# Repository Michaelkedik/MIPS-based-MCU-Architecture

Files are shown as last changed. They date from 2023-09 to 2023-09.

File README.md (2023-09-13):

# MIPS based MCU Architecture

In this project, I developed an MCU based on the MIPS architecture, incorporating Memory-Mapped I/O, a Basic Timer, and an Interrupt Controller.
The CPU uses a Single Cycle MIPS architecture and is capable of performing full instruction set of simple MIPS.
The design is located on Altera Board and the MIPS architecture is Harvard architecture in order to increase the throughput.
The architecture includes a MIPS ISA compatible CPU with data and program memory for hosting data and code.
The CPU have a standard MIPS register file. The top level and the MIPS core are structural. 
The figure below illustrates the design.



The GPIO is a simple decoder with buffer registers mapped to data address (Higher than data memory) that enables the CPU to output data to LEDs and 7-Segment and to read the Switches state.
The Data Address Space is 32-bit WORD aligned where the address word is 0 ... 0 A11 ... A0 with partial mapping that contains Data Memory and Memory Mapped I/O.
The figure below illustrates the design.



The Basic Timer was designed to facilitate standard timer functions as well as the generation of PWM signals through the utilization of the output compare mode.
The figure below illustrates the design.



The Interrupt Controller was specifically crafted to manage a range of interrupt types, including those originating from the basic timer.
The figure below illustrates the design.



## Description

The repositories in this project serve the following purposes:

**DUT:** This repository contains VHDL codes for the top entity and components. These codes can be compiled using ModelSim and Quartus via change of basic parameters.

**DOC:** This repository contains project documentation and a README file that provides an explanation of the VHDL files' purpose.

**CODE:** This repository contains assembly code used for verifying the design's functionality.

**TB:** This repository contains Testbench files that were used for ModelSim verification of the design.

**SIM:** This repository contains ".do" files used for ModelSim simulation.

**QUARTUS:** This repository contains project files such as ".sof," SDC, and STP files, which are used for Quartus compilation and verification of the design.

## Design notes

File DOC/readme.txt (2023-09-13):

1)Top- The top entity, Synchronizes the MIPS, GPIO and the BUS
2)MIPS - The CPU, Synchronizes all the other components of the CPU
3)IFETCH - Get the instruction and advance the PC according to the relevant adress
4)IDECODE - Decode the instruction and read and write from the register file
5)DMEMORY- Read or write from the data memory
6)EXECUTE- Performs all the logic or arithmetic actions
7)CONTROL - Produces the control signals that are needed for the instructions to be executed
8)GPIO - General IO Component, Synchronizes all the IO Components
9)BidirPin - Used as data bus
10)Timer - Basic timer used for interrupts and to generate PWM signal using output compare mode
11)INTCTL - Interrupt controller, responsible for handling the interrupts
12)Hex - Decoder for the HEX outputs
13)D_latch - a simple D_latch, used in the INTCTL

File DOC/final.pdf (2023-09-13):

# מעבדת ארכיטקטורת מעבדים מתקדמת ומאיצי חומרה

# פרויקט גמר

# מיכאל קדיק 316645415 עמית ניסני 205664345

## תיאור הפרויקט

,Single Cycle MIPS על | המבוסס | CPU MIPS based MCU | לייצר | התבקשנו | זה | בפרויקט
המשתמש בO/I Mapped Memory ובעל תמיכה בפסיקות. לשם כך, יצרנו יחידות כמו GPIO, INTCTL ו-Timer בכדי לאפשר את כל הנדרש.

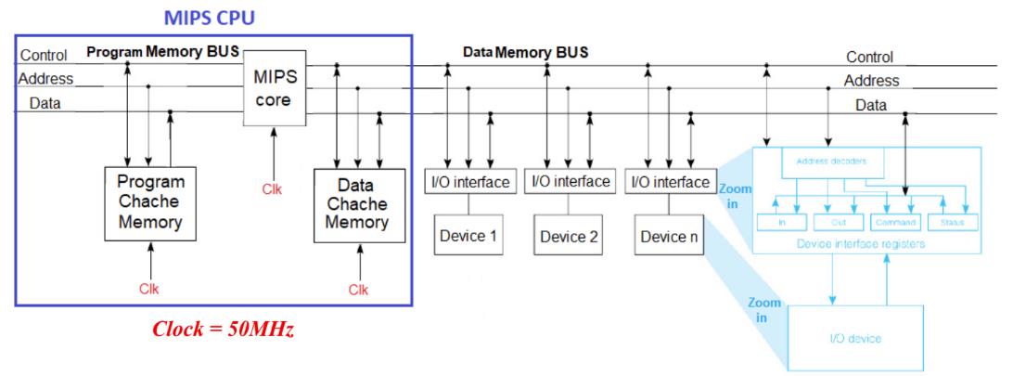
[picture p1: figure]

את ה-GPIO מימשנו עפ"י הנדרש בפרויקט כפי שצוין באיור הבא.

Figure 1. System architecture

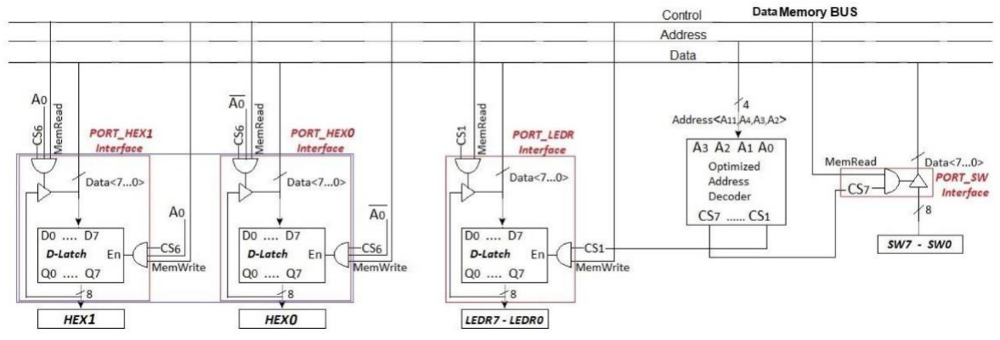
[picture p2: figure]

Figure 2. GPIO peripheral connection using Memory Mapped I/O

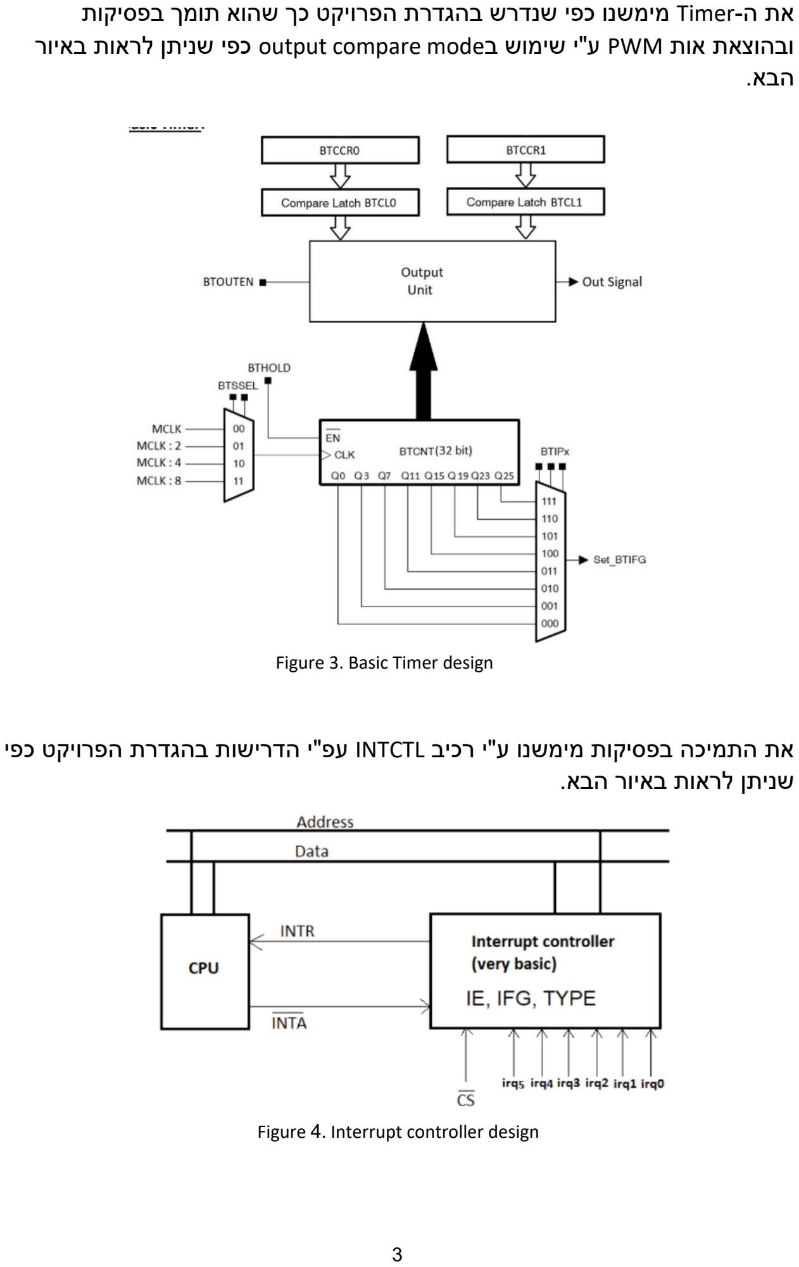
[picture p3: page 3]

את ה-Timer מימשנו כפי שנדרש בהגדרת הפרויקט כך שהוא תומך בפסיקות ובהוצאת אות PWM ע"י שימוש בmode compare output כפי שניתן לראות באיור הבא.

את התמיכה בפסיקות מימשנו ע"י רכיב INTCTL עפ"י הדרישות בהגדרת הפרויקט כפי שניתן לראות באיור הבא.

Figure 3. Basic Timer design

Figure 4. Interrupt controller design

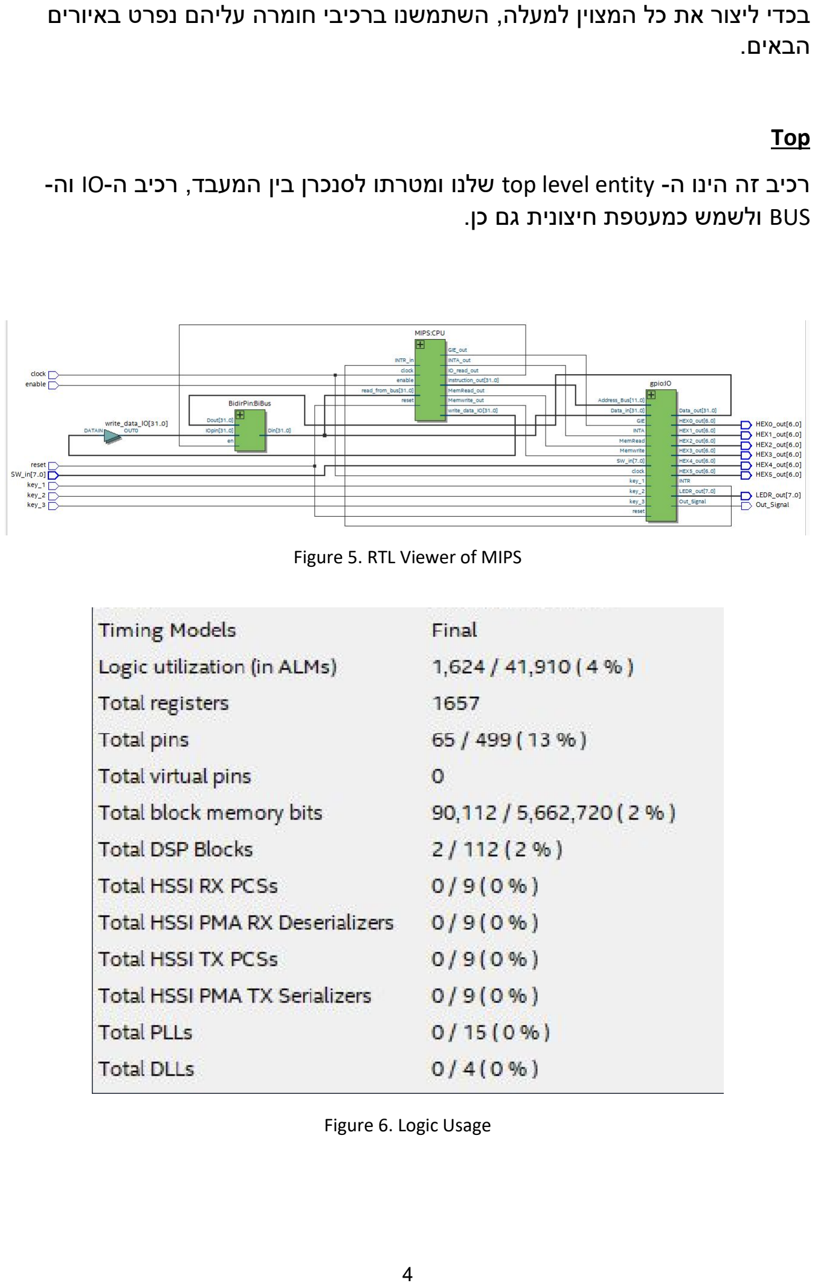
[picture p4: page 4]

בכדי ליצור את כל המצוין למעלה, השתמשנו ברכיבי חומרה עליהם נפרט באיורים הבאים.

Top

רכיב זה הינו ה- entity level top שלנו ומטרתו לסנכרן בין המעבד, רכיב ה-IO וה-BUS ולשמש כמעטפת חיצונית גם כן.

Figure 5. RTL Viewer of MIPS

Figure 6. Logic Usage

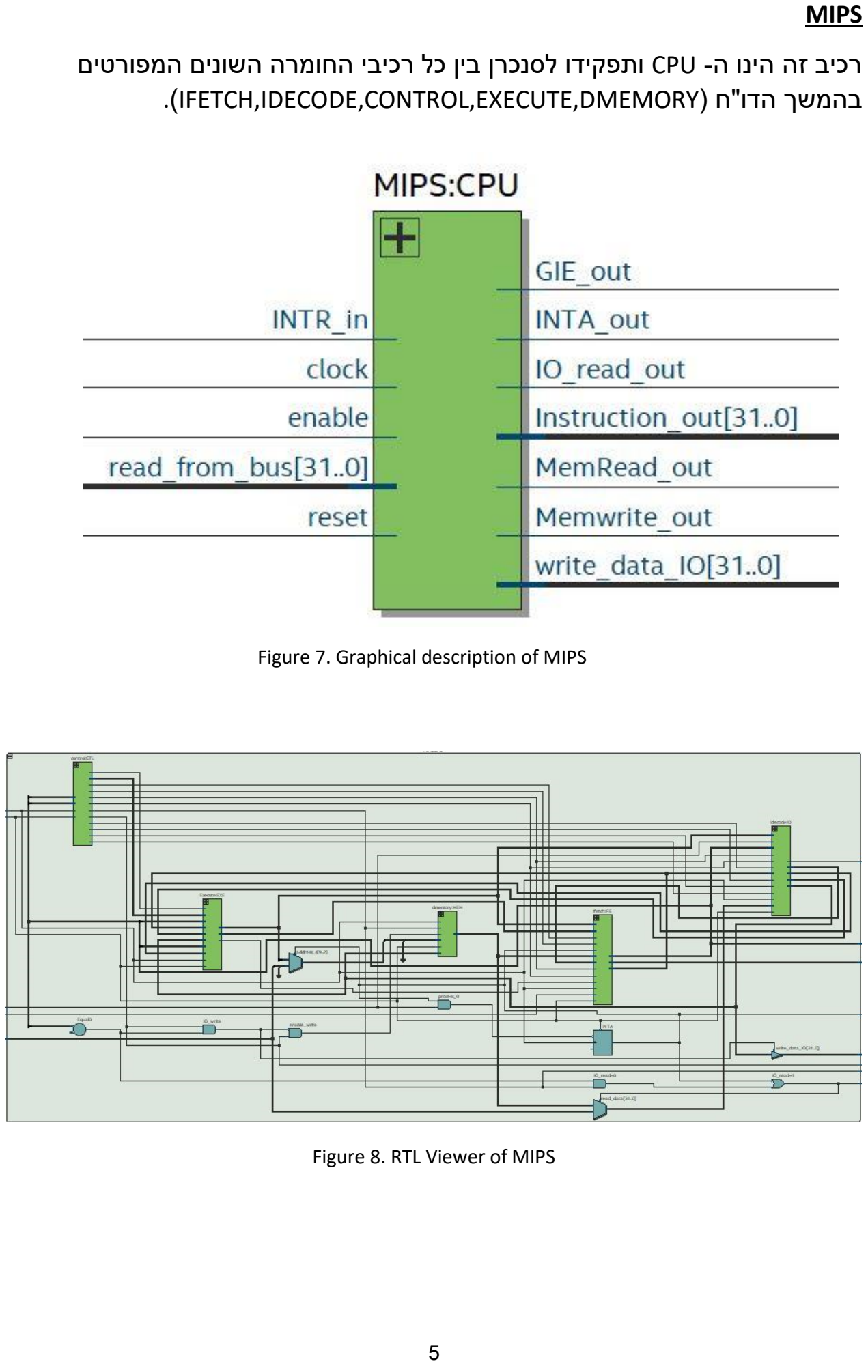
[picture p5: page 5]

MIPS

רכיב זה הינו ה- CPU ותפקידו לסנכרן בין כל רכיבי החומרה השונים המפורטים
.)IFETCH,IDECODE,CONTROL,EXECUTE,DMEMORY( ח"הדו | בהמשך

Figure 7. Graphical description of MIPS

Figure 8. RTL Viewer of MIPS

Name | Direction | Size | Functionality
clock | IN | 1 | שעון
reset | IN | 1 | אתחול
enable | IN | 1 | PC אפשור
INTR_in | IN | 1 | בקרה
read_from_bus | IN | 32 | BUS -מה מידע קריאת
IO_read_out | OUT | 1 | בקרה
write_data_IO | OUT | 32 | BUS -ה אל מידע כתיבת
| | | פקודה שמתבצעת כרגע 32 OUT out_Instruction
MemRead_out | OUT | 1 | בקרה
Memwrite_out | OUT | 1 | בקרה
INTA_out | OUT | 1 | בקרה
GIE_out | OUT | 1 | בקרה

Table 1. Port Table of MIPS

IFETCH

תפקידו של רכיב זה הוא להביא את הפקודה שיש לבצע ולקדם את ה-pc לפקודה הבאה )שאינה בהכרח הפקודה העוקבת, כמו למשל אם יש jump).

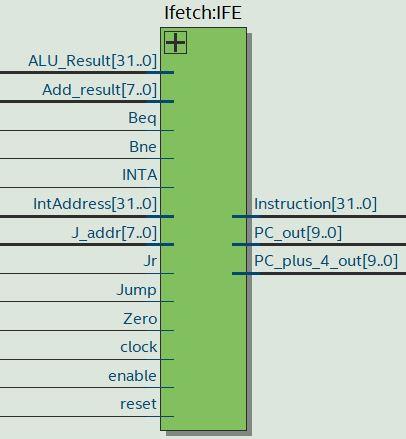
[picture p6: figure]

Figure 9. Graphical description of IFETCH

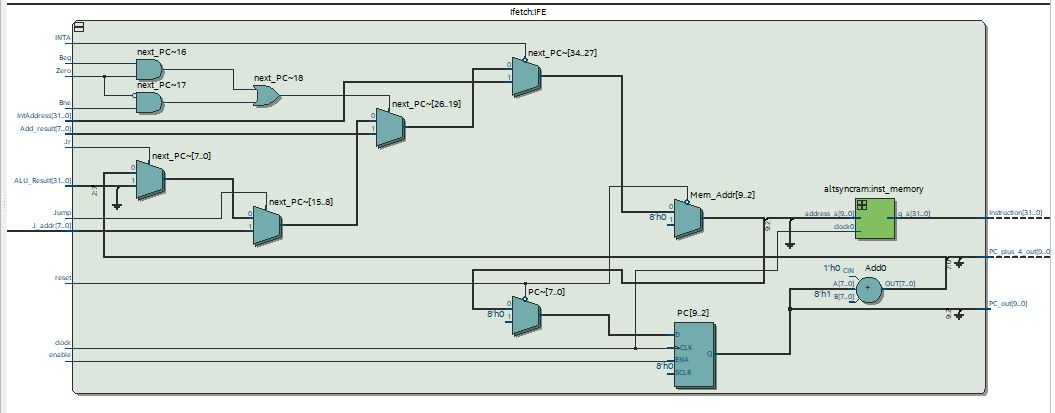
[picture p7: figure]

Figure 10. RTL Viewer of IFETCH

Name | Direction | Size | Functionality
clock | IN | 1 | שעון
reset | IN | 1 | אתחול
enable | IN | 1 | PC אפשור
Add_result | IN | 8 | הסתעפות כתובת
| | | משמש לפקודת קפיצה 32 IN Result_ALU
IntAddress | IN | 32 | כתובת למיקופ בוקטור הפסיקה
J_addr | IN | 8 | קפיצה כותבת
INTA | IN | 1 | בקרה
Jump | IN | 1 | בקרה
Zero | IN | 1 | בקרה
Beq | IN | 1 | בקרה
Bne | IN | 1 | בקרה
Jr | IN | 1 | בקרה
| | | פקודה לביצוע 32 OUT Instruction
| | | כתובת של פקודה הבאה 10 OUT out_4_plus_PC
| | | כתובת של פקודה נוכחית 10 OUT out_PC

Table 2. Port Table of IFETCH

IDECODE

תפקידו של רכיב זה הוא לפענח את הפקודה שיש לבצע , בנוסף ברכיב זה נמצא הfile register ולכן מתבצעת בו גם כתיבה לרגיסטרים.

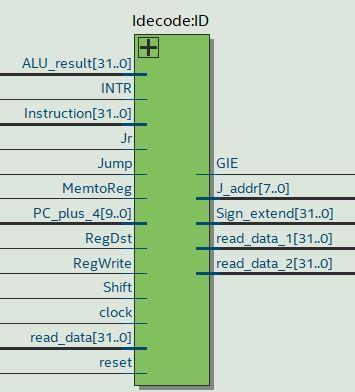
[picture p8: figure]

Figure 11. Graphical description of IDECODE

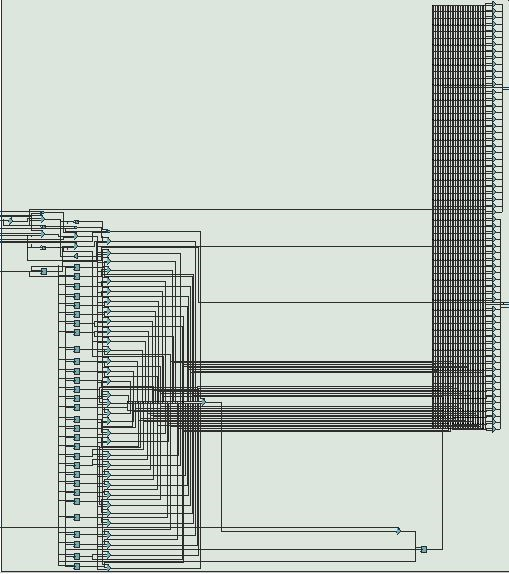
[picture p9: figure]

Figure 12. RTL Viewer of IDECODE

Name | Direction | Size | Functionality
clock | IN | 1 | שעון
reset | IN | 1 | אתחול
| | | הפקודה הנוכחית לפענוח 32 IN Instruction
read_data | IN | 32 | המידע בכתיבה לרגיסטרים
ALU_result | IN | 32 | ALU -ב הפעולה תוצאת
RegWrite | IN | 1 | בקרה
MemtoReg | IN | 1 | בקרה
RegDst | IN | 1 | בקרה
Jump | IN | 1 | בקרה
Jr | IN | 1 | בקרה
Shift | IN | 1 | בקרה
INTR | IN | 1 | בקרה
PC_plus_4 | IN | 10 | כתובת של הפקודה הבאה לביצוע
read_data_1_out | OUT | 32 | 1 מרגיסטר המידע
read_data_2_out | OUT | 32 | 2 מרגיסטר המידע
Sign_extend | OUT | 32 | סיגנל מורחב בהתאם לסימן
J_addr | OUT | 8 | קפיצה כתובת
GIE | OUT | 1 | בקרה

Table 3. Port Table of IDECODE

CONTROL

תפקידו של רכיב זה הוא לייצר את קווי הבקרה בהתאם לפקודה הנוכחית.

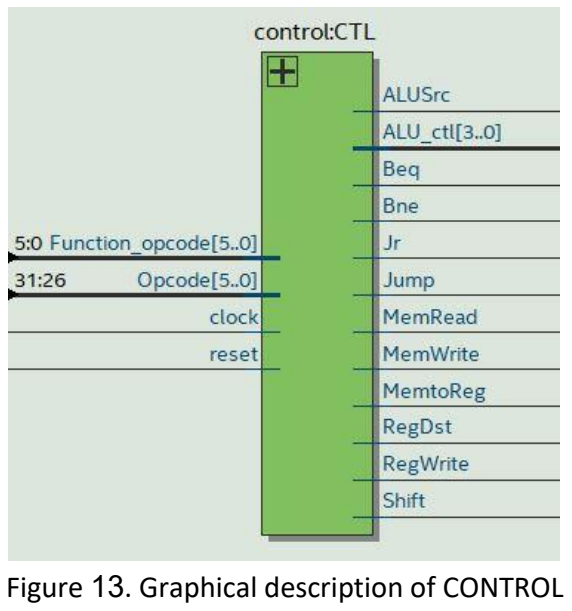
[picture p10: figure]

Figure 13. Graphical description of CONTROL

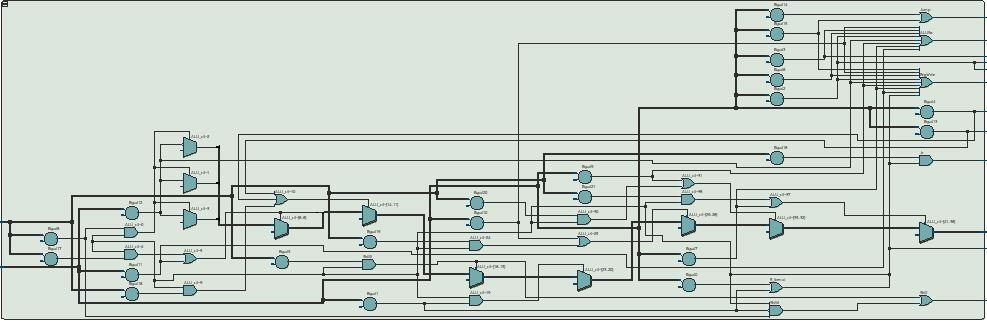
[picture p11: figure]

Figure 14. RTL Viewer of CONTROL

Name | Direction | Size | Functionality
clock | IN | 1 | שעון
reset | IN | 1 | אתחול
| | | ביטים 26-31 בפקודה 6 IN Opcode
Function_opcode | IN | 6 | בפקודה 0-5 ביטים
RegDst | OUT | 1 | קו בקרה לבחירת כתובת יעד הכתיבה לרגיסטר
ALUSrc | OUT | 1 | קו בקרה הבורר איזה מידע יכנס לכניסה B ב-ALU
MemtoReg | OUT | 1 | קו בקרה הבורר בין המידע שיכתב לתוך הרגיסטרים )מהזכרון או מה-ALU)
RegWrite | OUT | 1 | קו בקרה הבורר את כתובת הרגיסטר לכתיבה
MemRead | OUT | 1 | קו בקרה המבחין האם יש לקרוא מהזכרון
MemWrite | OUT | 1 | קו בקרה המבחין האם יש לכתוב לזכרון
Shift | OUT | 1 | קו בקרה המבחין האם יש פעולת shift
Jump | OUT | 1 | קו בקרה המבחין האם יש פעולת קפיצה
Jr | OUT | 1 | קו בקרה המבחין האם יש פעולת קפיצה לתוך ערך השמור ברגיסטר
Beq | OUT | 1 | קו בקרה המבחין האם יש פעולת הסתעפות
Bne | OUT | 1 | קו בקרה המבחין האם יש פעולת הסתעפות
ALU_ctl | OUT | 4 | קו בקרה הבורר איזה פעולה יש לעשות ב-ALU

Table 4. Port Table of CONTROL

EXECUTE

תפקידו של רכיב זה הוא ביצוע הפעולות הנדרשות בכדי לבצע את הפקודה.

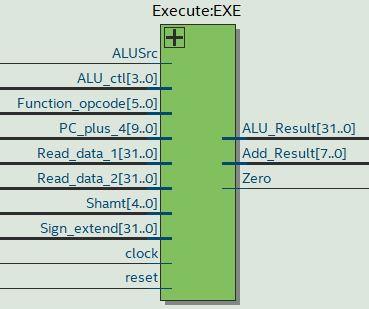
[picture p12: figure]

Figure 15. Graphical description of EXECUTE

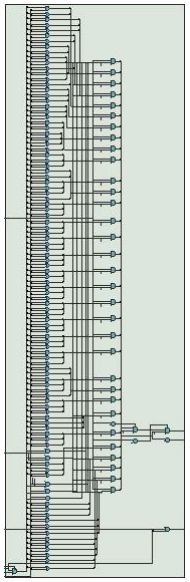
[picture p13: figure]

Figure 16. RTL Viewer of EXECUTE

Name | Direction | Size | Functionality
clock | IN | 1 | שעון
reset | IN | 1 | אתחול
Read_data_1 | IN | 32 | 1 מרגיסטר מידע
Read_data_2 | IN | 32 | 2 מרגיסטר מידע
Sign_extend | IN | 32 | מידע משדה הimmidiate מורחב
| | | ביטים 0-5 של הפקודה 6 IN opcode_Function
ALUSrc | IN | 1 | בקרה
PC_plus_4 | IN | 10 | כתובת של הפקודה הבאה לביצוע
| | | ביטים 6-10 בפקודה 5 IN Shamt
ALU_ctl | IN | 4 | בורר איזה פקודה יש לבצע ב- ALU
ALU_Result | OUT | 32 | ALU -ה תוצאת
Add_Result | OUT | 8 | תוצאת חישוב כתובת ההסתעפות
Zero | OUT | 1 | בקרה

Table 5. Port Table of EXECUTE

DMEMORY

תפקידו של רכיב זה הוא לבצע קריאה מהזכרון או כתיבה לזכרון.

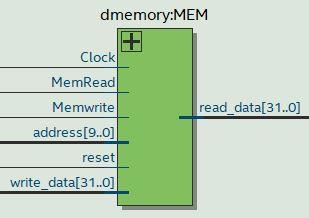
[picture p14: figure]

Figure 17. Graphical description of DMEMORY

Figure 18. RTL Viewer of DMEMORY

Name | Direction | Size | Functionality
clock | IN | 1 | שעון
reset | IN | 1 | אתחול
| | | כתובת כתיבה לזכרון 10 IN address
| | | מידע שנכתב לזכרון 32 IN data_write
MemRead | IN | 1 | בקרה
Memwrite | IN | 1 | בקרה
| | | מידע שיוצא מהזכרון 32 OUT data_read

Table 6. Port Table of DMEMORY

GPIO

תפקידו של רכיב זה הוא לסנכרן בין כל רכיבי ה-IO השונים והעברת המידע מהם אל ה-BUS.

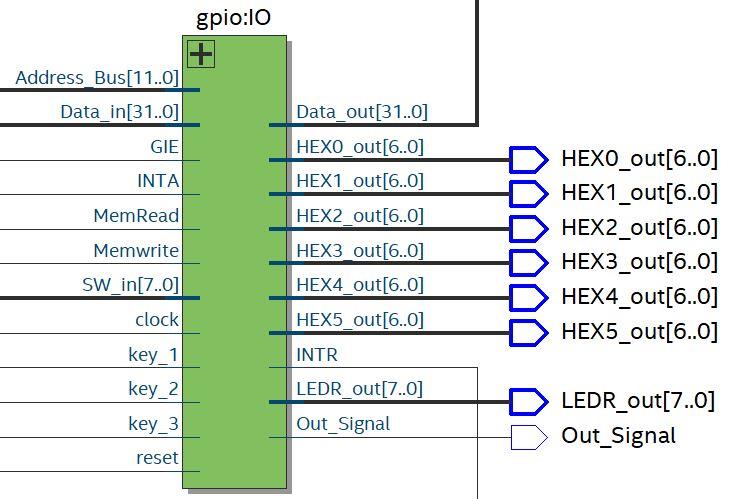
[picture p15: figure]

Figure 19. Graphical description of GPIO

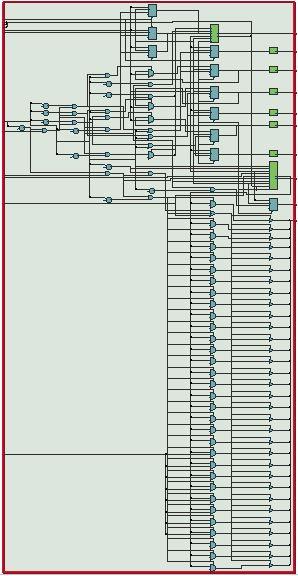
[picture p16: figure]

Figure 20. RTL Viewer of GPIO

Name | Direction | Size | Functionality
| | | מידע שנכנס לרכיב 32 IN in_Data
Address_Bus | IN | 12 | כתובת
MemRead | IN | 1 | בקרה
Memwrite | IN | 1 | בקרה
GIE | IN | 1 | אות בקרה המאפשר פסיקות גלובליות
INTA | IN | 1 | אות בקרה המגיע מהCPU ומעיד על אישור פסיקה
reset | IN | 1 | אתחול
clock | IN | 1 | שעון
key_1 | IN | 1 | 1 לחצן
key_2 | IN | 1 | 2 לחצן
key_3 | IN | 1 | 3 לחצן
SW_in | IN | 8 | מתגים
| | | מידע שיוצא מהרכיב 32 OUT out_Data
HEX0_out | OUT | 7 | מידע לאחר קידוד שנכתב על ה-HEX
HEX1_out | OUT | 7 | מידע לאחר קידוד שנכתב על ה-HEX
HEX2_out | OUT | 7 | מידע לאחר קידוד שנכתב על ה-HEX
HEX3_out | OUT | 7 | מידע לאחר קידוד שנכתב על ה-HEX
HEX4_out | OUT | 7 | מידע לאחר קידוד שנכתב על ה-HEX
HEX5_out | OUT | 7 | מידע לאחר קידוד שנכתב על ה-HEX
| | | מידע שמופיע על הלדים 8 OUT out_LEDR
INTR | OUT | 1 | קו בקרה המודיע ל CPU שיש בקשה לפסיקה
Out_Signal | OUT | 1 | PWM אות

Table 7. Port Table of GPIO

TIMER

תפקידו של רכיב זה הוא לשמש בתור Timer Basic המאפשר יצירת פסיקות בהתאם לקינפוגים שונים, כמו כן ניתן להוציא בעזרתו אות PWM.

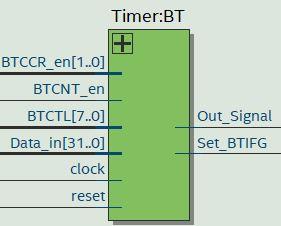
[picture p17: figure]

Figure 21. Graphical description of TIMER

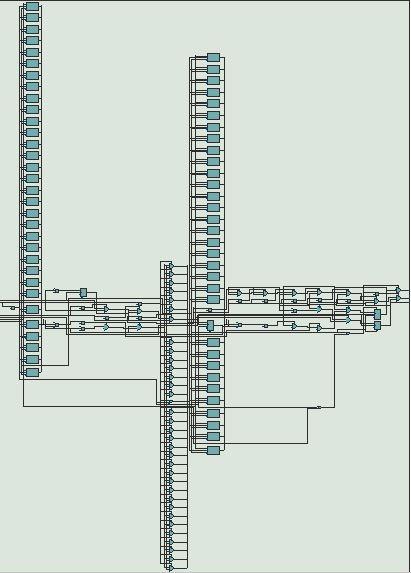
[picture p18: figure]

Figure 22. RTL Viewer of TIMER

Name | Direction | Size | Functionality
| | | מידע הנכנס לרכיב 32 IN in_Data
BTCTL | IN | 8 | רגיסטר שבעזרתו מקונפג השעון
BTCCR_en | IN | 2 | אפשור כתיבה לרגיסטרים 0BTCL, BTCL1
BTCNT_en | IN | 1 | אפשור כתיבה לרגיסטר BTCNT
reset | IN | 1 | אתחול
clock | IN | 1 | שעון
BTCNT_out | OUT | 32 | ערך הספירה של הטיימר
| | | פסיקה של השעון 1 OUT BTIFG_Set
Out_Signal | OUT | 1 | אות PWM שנוצר ע"י הטיימר

Table 8. Port Table of TIMER

INTCTL

תפקידו של רכיב זה הוא לנהל ולשלוט על כל הפסיקות.

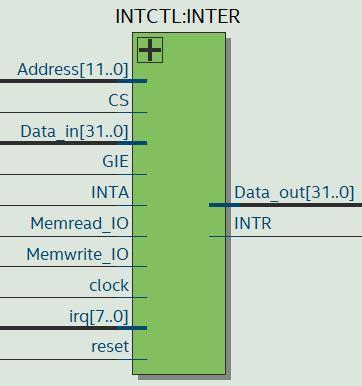
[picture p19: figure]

Figure 23. Graphical description of INTCTL

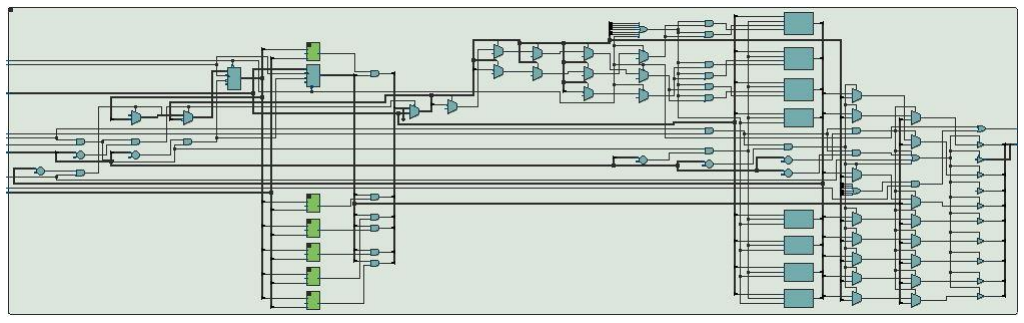
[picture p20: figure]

Figure 24. RTL Viewer of INTCTL

Name | Direction | Size | Functionality
| | | מידע הנכנס לרכיב 32 IN in_Data
Address | IN | 12 | כתובת
| | | מודיע על בקשות פס יקה 8 IN irq
INTA | IN | 1 | בקרה
reset | IN | 1 | אתחול
clock | IN | 1 | שעון
| | | מעיד על פניה לרכיב 1 IN cs
Memwrite_IO | IN | 1 | בקרה
Memread_IO | IN | 1 | בקרה
GIE | IN | 1 | בקרה
| | | מידע היוצא מהרכיב 32 OUT out_Data
INTR | OUT | 1 | בקרה

Table 9. Port Table of INTCTL

D_LATCH

רכיב עזר שמשומש בבקר הפסיקות.

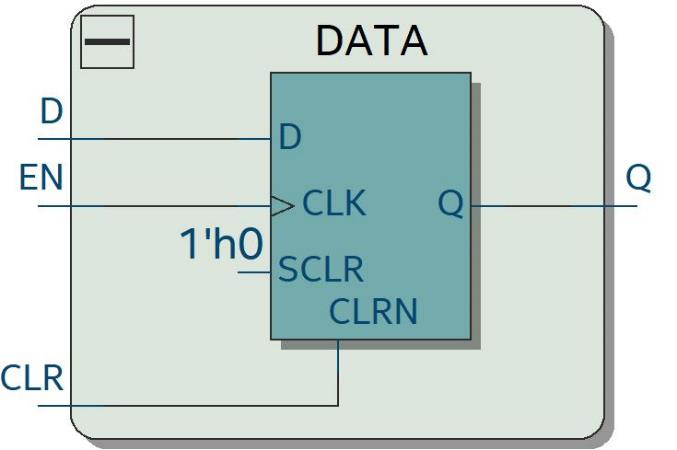
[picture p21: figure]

Name | Direction | Size | Functionality
D | IN | 1 | קבוע 1
| | | אפשור כתיבה 1 IN EN
CLR | IN | 1 | איפוס
Q | OUT | 1 | מוצא

Figure 25. Graphical description of D_LATCH

Figure 26. RTL Viewer of D_LATCH

Table 10. Port Table of D_LATCH

HEX

רכיב עזר המשמש לקידוד המידע שמוצג ב-HEX.

Name | Direction | Size | Functionality
| | | ערך שרוצים להציג 4 IN input_Hex
Hex_output | OUT | 7 | להצגה המרה

Figure 28. RTL Viewer of HEX

Table 11. Port Table of HEX

BidirPin

רכיב שתפקידו לשמש כ-bus Data ולהעביר מידע בין ה-CPU ורכיבי ה-IO.

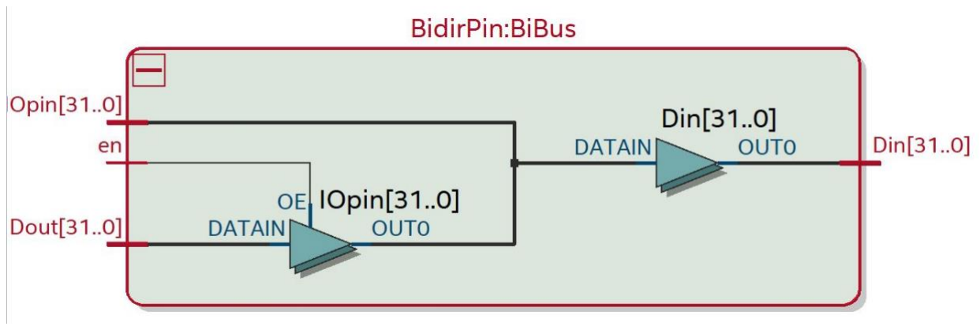
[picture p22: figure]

Name | Direction | Size | Functionality
Dout | IN | 32 | מידע היוצא מהרכיב אל ה-BUS
| | | אפשור כתיבה ל-BUS 1 IN en
Din | OUT | 32 | מידע הנכנס מה-BUS אל הרכיב
IOpin | INOUT | 32 | BUS-ה

Figure 29. Graphical description of BidirPin

Figure 30. RTL Viewer of BidirPin

Table 12. Port Table of BidirPin

כמו כן, בדקנו את ה- fmax ואת המסלול הקריטי עבור המימוש שלנו בפרויקט . ניתן לראות אותם באיורים הבאים.

ניתן לראות כי המסלול הקריטי עובר בכל הרכיבים, כצפוי ממעבד Cycle Single. כמו כן, ניתן לראות כי על אף שהוספנו רכיבי IO, המסלול הקריטי הוא עדיין נמצא ב-CPU מכיוון שבמסלול זה מתבצעת גם קריאה מהז י כרון וגם כתיבה חזרה אל ה-RF.

בכדי לבדוק את נכונות המימוש שלנו ושאכן המעבד מבצע את כל הפקודות כנדרש וכל רכיבי החומרה , כולל רכיבי ה- IO מבצעים את תפקידם הרצנו את הקודים לבדיקה שפורסמו . חלק מהתוצאות מצורפות לדו"ח באיורים הבאים.

תחילה הרצנו את asm3.test ובדקנו שכל הערכים נכנסים כמו שצריך למקומות המיועדים להם. את התוצאות ניתן לראות באיור הבא.

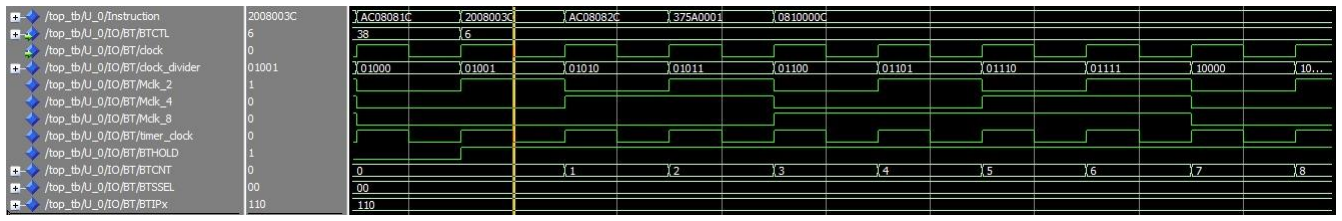
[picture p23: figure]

Figure 33. Modelsim simulation results

Figure 31. Fmax

Figure 32. Critical Path

בתוכנית ז ו בדקנו שאכן כל הערכים שצריכים להכנס את הרגיסטרים וקווי הברקה של הטיימר אכן נכתבים כמו שצריך. ניתן לראות שאכן ה- BTCTL מקבל את הערך 06x0 כנדרש. בהתאם לכך ביטי הקנפוג משתנים בהתאם, 00 = BTSSEL, 110 = BTIP. כמו כן, ניתן לראות שהשעון שבאמצעותו הטיימר סופר , clock_timer הוא בדיוק כמו השעון הרגיל בהתאם לBTSSEL. עם זאת, ניתן לר אות באמצעות i_Mclk שנוצרים כל השעונים הנדרשים בהתאם לחלוקה, ולכן עבור BTSSEL אחר היה נבחר שעון נכון גם כן. לבסוף, ניתן לראות שלאחר הקנפוג ואפשור הטיימר השעון אכל מתחיל לספור עפ"י הערך של BTCNT.

בנוסף, בדקנו את נכונות המימוש שלנו באמצעות הTap Signal ב- Quartus. מכיוון שלא מצאנו קודים לבדיקה שבודקים את היווצרות אות ה-PWM מהטיימר, כתבנו קוד קצר לבדיקה של דבר זה. ניתן לראות את התוצאות באיור הבא.

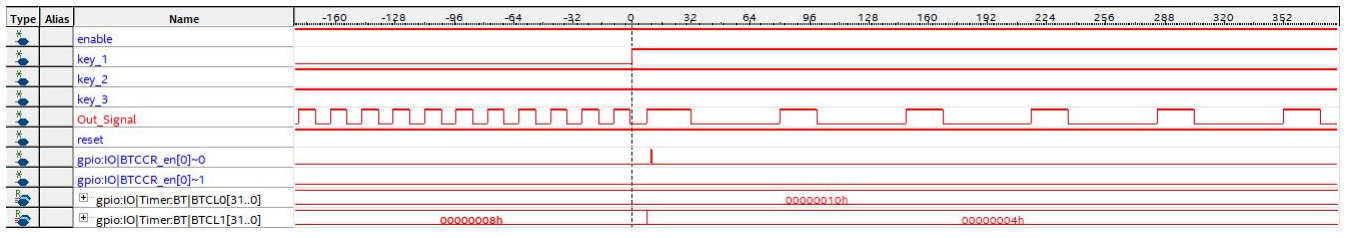
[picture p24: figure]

ניתן לראות שאכן נוצר אות PWM בcycle Duty מסוים בהתאם לערכים שנכנסו ל -0BTCL ו- 1BTCL. כמו כן, לאחר לחיצה על כפתור מסוים, ניתן לראות שהערך של 1BTCL קטן , ולכן הזמן בין 0BTCL ל – 1BTCL גדל, כלומר ערך האות הוא ,0 וה- Duty cycle משתנה, בהתאם למה שהיינו מצפים לראות.

Figure 34. Signal Tap Verification

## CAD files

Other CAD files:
Quartus/stp1.stp

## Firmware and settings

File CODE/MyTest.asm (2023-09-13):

#--------------------------------------------------------------
#		    MEMORY Mapped I/O
#--------------------------------------------------------------
#define PORT_LEDR[7-0] 0x800 - LSB byte (Output Mode)
#------------------- PORT_HEX0_HEX1 ---------------------------
#define PORT_HEX0[7-0] 0x804 - LSB byte (Output Mode)
#define PORT_HEX1[7-0] 0x805 - LSB byte (Output Mode)
#------------------- PORT_HEX2_HEX3 ---------------------------
#define PORT_HEX2[7-0] 0x808 - LSB byte (Output Mode)
#define PORT_HEX3[7-0] 0x809 - LSB byte (Output Mode)
#------------------- PORT_HEX4_HEX5 ---------------------------
#define PORT_HEX4[7-0] 0x80C - LSB byte (Output Mode)
#define PORT_HEX5[7-0] 0x80D - LSB byte (Output Mode)
#--------------------------------------------------------------
#define PORT_SW[7-0]   0x810 - LSB byte (Input Mode)
#--------------------------------------------------------------
#define PORT_KEY[3-1]  0x814 - LSB nibble (3 push-buttons - Input Mode)
#--------------------------------------------------------------
#define UCTL           0x818 - Byte 
#define RXBF           0x819 - Byte 
#define TXBF           0x81A - Byte
#--------------------------------------------------------------
#define BTCTL          0x81C - LSB byte 
#define BTCNT          0x820 - Word 
#define BTCCR0         0x824 - Word 
#define BTCCR1         0x828 - Word 
#--------------------------------------------------------------
#define IE             0x82C - LSB byte 
#define IFG            0x82D - LSB byte
#define TYPE           0x82E - LSB byte
#---------------------- Data Segment --------------------------
.data 
	IV: 	.word main            # Start of Interrupt Vector Table
		.word UartRX_ISR
		.word UartRX_ISR
		.word UartTX_ISR
	        .word BT_ISR
		.word KEY1_ISR
		.word KEY2_ISR
		.word KEY3_ISR

	N:	.word 0xB71B00
	
#---------------------- Code Segment --------------------------	
.text
main:	addi $sp,$zero,0x800 # $sp=0x800
	move $t3,$zero       # $t3=0
	move $t4,$zero       # $t4=0
	move $t5,$zero       # $t5=0
	move $t6,$zero       # $t6=0
	addi $t0,$zero,0x26  
	sw   $t0,0x81C       # BTOUTEN=0,BTIP=6,BTSSEL=0,BTHOLD=1,BTCTL=0x26
	sw   $0,0x820        # BTCNT=0
	addi $t0,$zero,0x10
	sw   $t0,0x824        # BTCCR0=0x10000
	addi $t0,$zero,0x8
	sw   $t0,0x828        # BTCCR1=0x8000
	sw   $0,0x82C        # IE=0
	sw   $0,0x82D        # IFG=0
	addi $t0,$zero,0x46  
	sw   $t0,0x81C       # BTOUTEN=1,BTIP=6,BTSSEL=0,BTHOLD=0,BTCTL=0x46,24MHz/2^24
	addi $t0,$zero,0x3C 
	sw   $t0,0x82C        # IE=0x3C
	ori  $k0,$k0,0x01     # EINT, $k0[0]=1 uses as GIE
	
L:	j    L  		     # infinite loop
	
KEY1_ISR:
	addi $t0,$zero,0x55  # fix from 0x15 to 0x55 enable
	sw   $t0,0x81C       # BTIP=5,BTSSEL=2,BTHOLD=0,BTCTL=0x15,24MHz/2^22
	addi $t4,$t4,1       # $t4=$t4+1
	sw   $t4,0x804       # write to PORT_HEX0[7-0]
	
	addi $t0,$zero,0x4
	sw   $t0,0x828        # BTCCR1=0x4000
	
	lw   $t1,0x82D # read IFG
	andi $t1,$t1,0xFFF7 
	sw   $t1,0x82D # clr KEY1IFG
	jr   $k1       # reti
	
KEY2_ISR:
	jr   $k1        # reti

KEY3_ISR:
	jr   $k1        # reti
		
BT_ISR:	
        jr   $k1        # reti

UartRX_ISR:	
        jr   $k1        # reti

UartTX_ISR:	
        jr   $k1        # reti        
                 
